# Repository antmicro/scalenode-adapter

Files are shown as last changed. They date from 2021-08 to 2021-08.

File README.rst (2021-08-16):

=================
Scalenode Adapter
=================

Copyright (c) 2021 `Antmicro <https://www.antmicro.com>`_

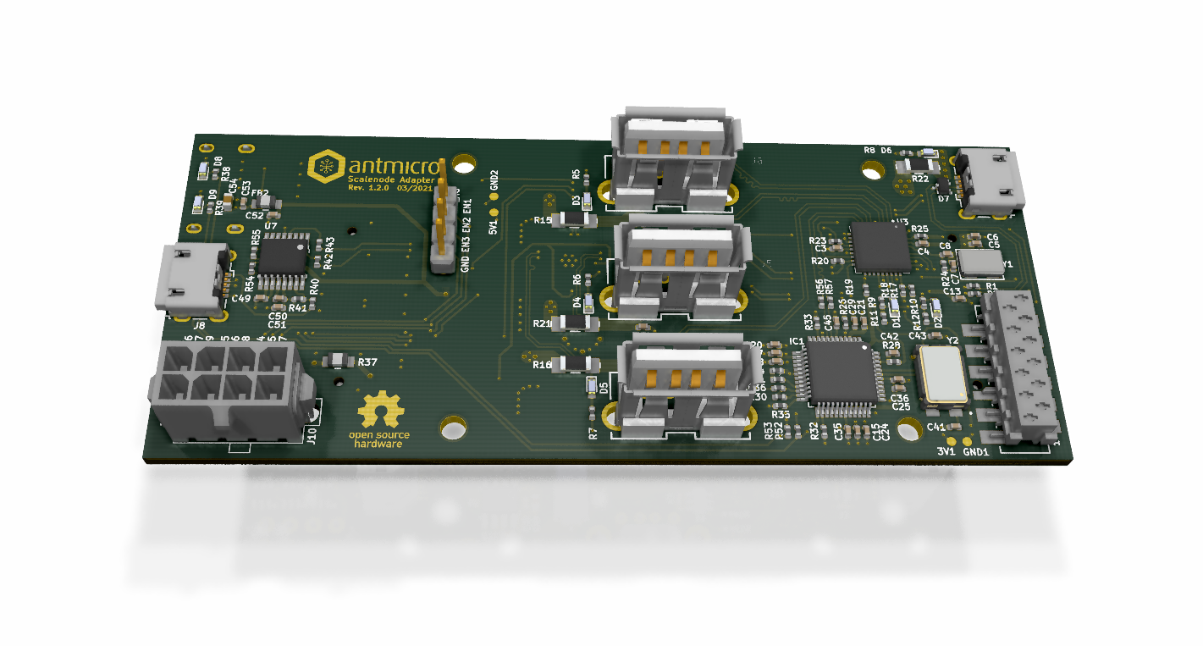
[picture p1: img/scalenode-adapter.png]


Overview
--------

This repository contains design files of the expansion card for the Antmicro's `Scalenode <https://github.com/antmicro/scalenode>`_ platform.
This expansion card exposes three USB host ports with independent supply current monitoring for each port.
This allows for using the Scalenode to interact with external, FPGA-driven evaluation boards such as the Digilent `Arty A7 <https://reference.digilentinc.com/programmable-logic/arty/start>`_ boards.
The design files were prepared in KiCad.
An initial production release for the design was fabricated as prototypes and these are now being tested.

Repository structure
--------------------
The main repository directory contains KiCad PCB project files, a LICENSE and README.
The remaining files are stored in the following directories:

* ``lib`` - contains the component libraries
* ``img`` - contains graphics for this README

Key Features
------------

* Expansion board for the Scalenode module
* Supports up to three Digilet Arty boards
* On-board current measurement circuitry

License
=======

`Apache-2.0 <LICENSE>`_

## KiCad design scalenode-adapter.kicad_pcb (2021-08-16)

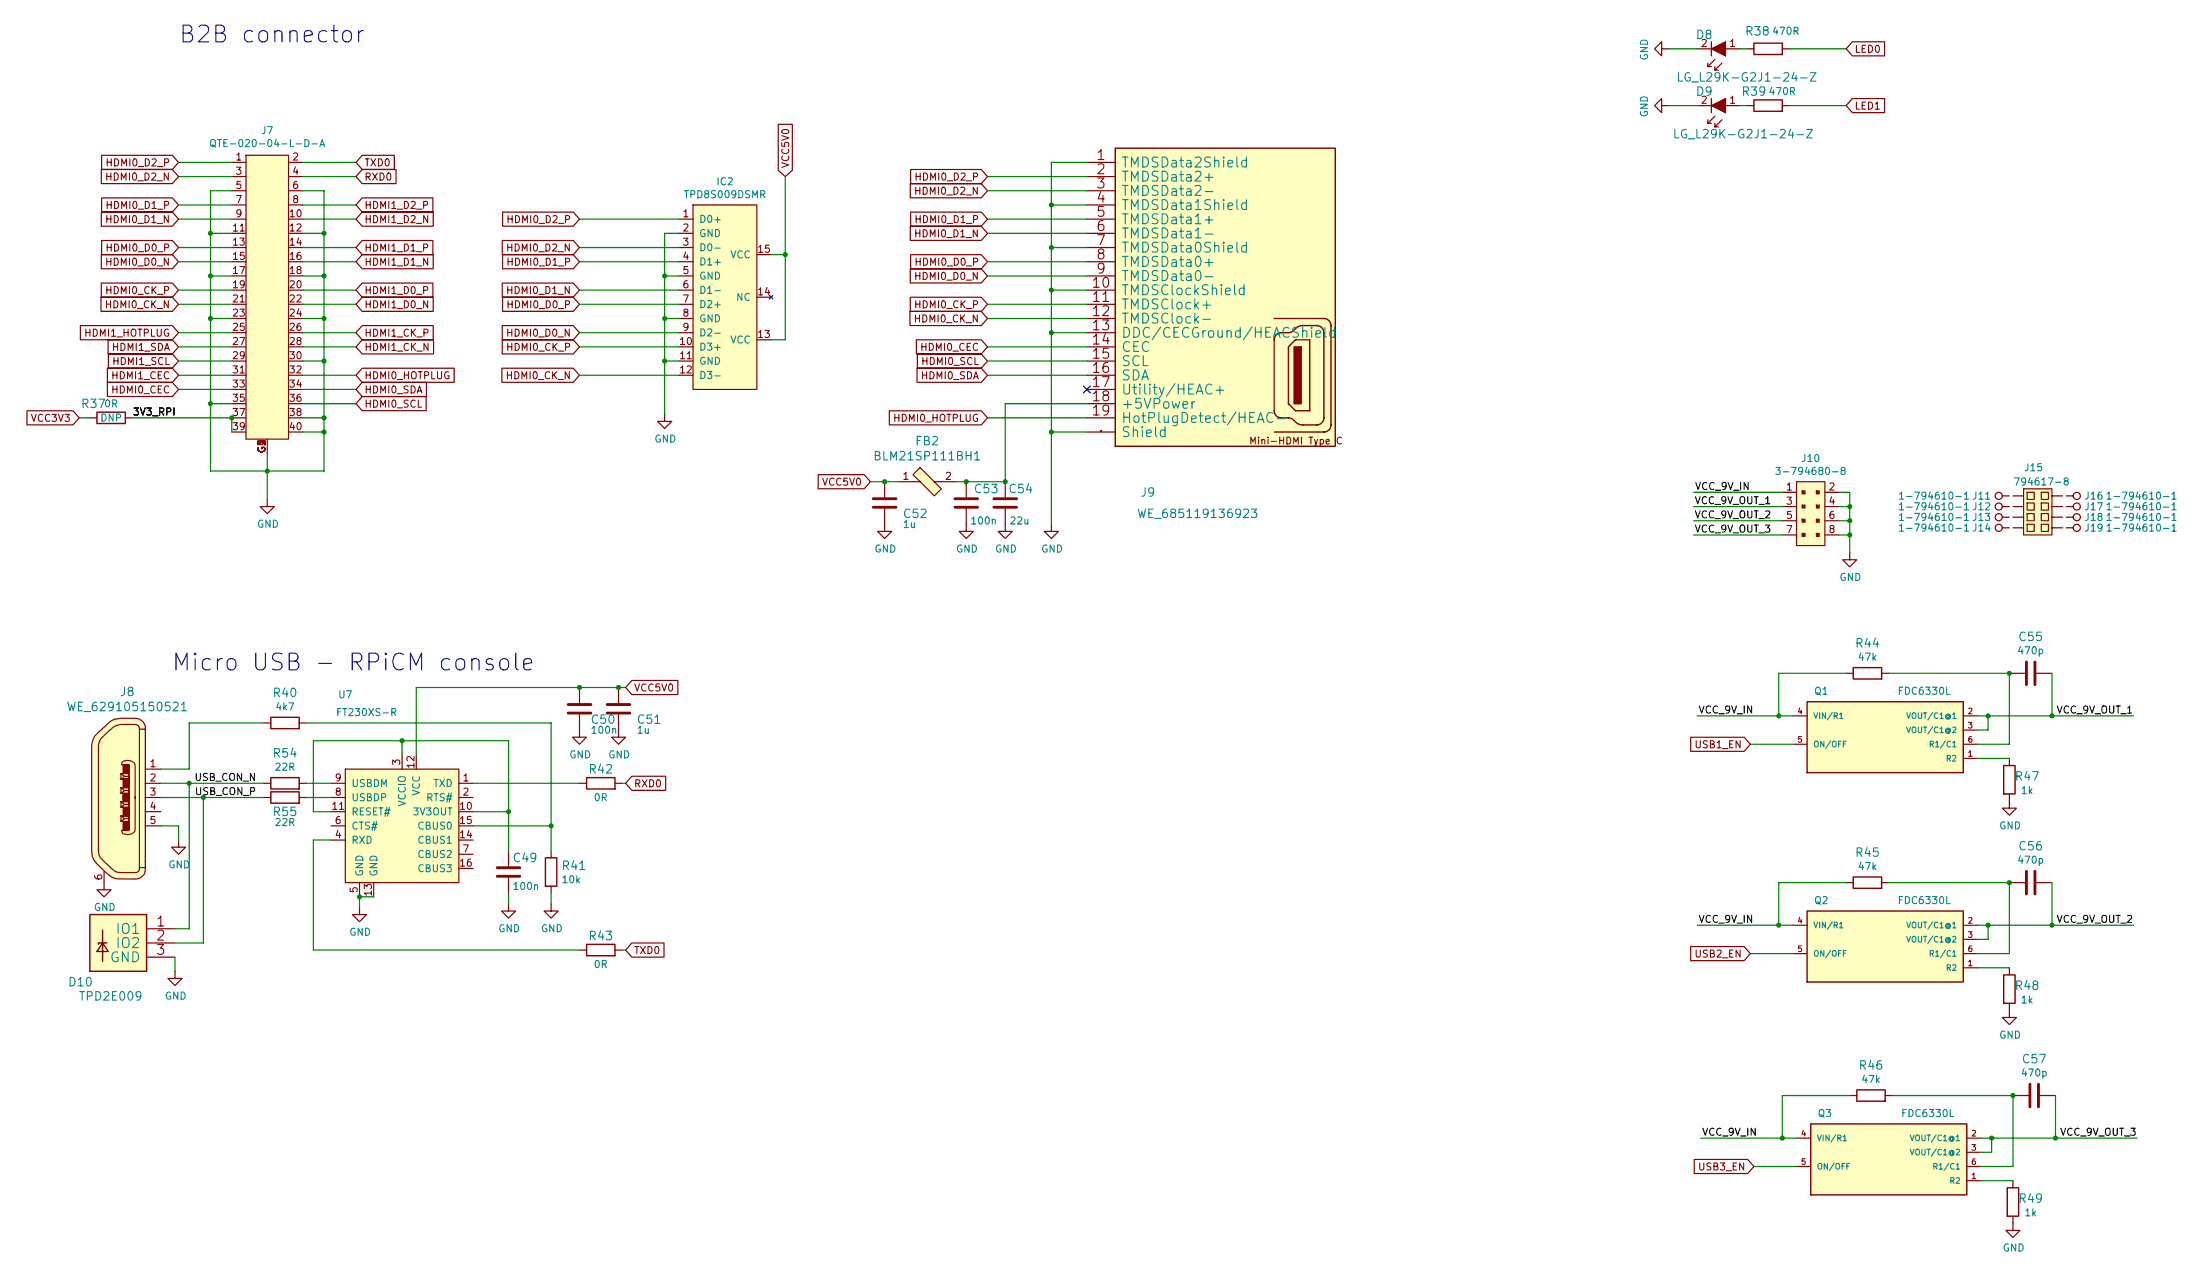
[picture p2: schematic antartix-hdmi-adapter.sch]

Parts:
C49, C50, C53: C_100n_0402; 0402-cap; MPN 0402X104K6R3CT
C51, C52: C_1u_0402; 0402-cap; MPN C1005X6S1A105K050BC
C54: C_22u_0603; 0603-cap; MPN GRM188R60J226MEA0D
C55, C56, C57: C_470p_0402; 0402-cap; MPN 0402B471K250CT
D8, D9: LG_L29K-G2J1-24-Z; LED_0603; MPN LG L29K-G2J1-24-Z
D10: TPD2E009; SOT-3; MPN TPD2E009DRTR
FB2: BLM21SP111BH1; 0805-res; MPN BLM21SP111BH1D
IC2: TPD8S009DSMR; R-PDSO-N15; MPN TPD8S009DSMR
J7: QTE-020-04-L-D-A; MPN QTE-020-04-L-D-A
J8: WE_629105150521; USB_Micro_B_Female_629105150521; MPN 629105150521
J9: WE_685119136923; MPN 685119136923
J10: 3-794680-8; MPN 3-794680-8
J11, J12, J13, J14, J16, J17, J18, J19: 1-794610-1; MPN 1-794610-1
J15: 794617-8; 3-794617-8; MPN 794617-8
Q1, Q2, Q3: FDC6330L; MPN FDC6330L
R37: R_0R_0805; 0805-res; MPN CRCW08050000Z0EA
R38, R39: R_470R_0402; 0402-res; MPN CRCW0402470RFKED
R40: R_4k7_0402; 0402-res; MPN ERJ2GEJ472X
R41: R_10k_0402; 0402-res; MPN CRCW040210K0FKEDHP
R42, R43: R_0R_0402; 0402-res; MPN ERJ2GE0R00X
R44, R45, R46: R_47k_0402; 0402-res; MPN MCMR04X4702FTL
R47, R48, R49: R_1k_0402; 0402-res; MPN CR0402-FX-1001GLF
R54, R55: R_22R_0402; 0402-res; MPN CRCW040222R0FKED
U7: FT230XS-R; SSOP-16_W3.90mm; MPN FT230XS-R

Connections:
/antartix hdmi adapter/3V3_RPI: J7.37, J7.39, R37.2
/antartix hdmi adapter/USB_CON_N: D10.1 (IO1), J8.2, R54.1
/antartix hdmi adapter/USB_CON_P: D10.2 (IO2), J8.3, R55.1
/antartix hdmi adapter/VCC_9V_IN: J10.1, Q1.4 (VIN/R1), Q2.4 (VIN/R1), Q3.4 (VIN/R1), R44.1, R45.1, R46.1
/antartix hdmi adapter/VCC_9V_OUT_1: C55.1, J10.3, Q1.2 (VOUT/C1@1), Q1.3 (VOUT/C1@2)
/antartix hdmi adapter/VCC_9V_OUT_2: C56.1, J10.5, Q2.2 (VOUT/C1@1), Q2.3 (VOUT/C1@2)
/antartix hdmi adapter/VCC_9V_OUT_3: C57.1, J10.7, Q3.2 (VOUT/C1@1), Q3.3 (VOUT/C1@2)
GND: C49.2, C50.2, C51.2, C52.2, C53.2, C54.1, D8.2, D9.2, D10.3 (GND), IC2.2 (GND), IC2.5 (GND), IC2.8 (GND), IC2.11 (GND), J7.5, J7.6, J7.11, J7.12, J7.17, J7.18, J7.23, J7.24, J7.30, J7.35, J7.38, J7.40, J7.G1, J7.G2, J7.G3, J7.G4, J8.5, J8.6, J9.1 (TMDSData2Shield), J9.4 (TMDSData1Shield), J9.7 (TMDSData0Shield), J9.10 (TMDSClockShield), J9.13 (DDC/CECGround/HEACShield), J9.Shell (Shield), J10.2, J10.4, J10.6, J10.8, R41.2, R47.2, R48.2, R49.2, U7.5 (GND), U7.13 (GND); also elsewhere on the board
HDMI0_CEC: J7.33, J9.14 (CEC)
HDMI0_CK_N: IC2.12 (D3-), J7.21, J9.12 (TMDSClock-)
HDMI0_CK_P: IC2.10 (D3+), J7.19, J9.11 (TMDSClock+)
HDMI0_D0_N: IC2.9 (D2-), J7.15, J9.9 (TMDSData0-)
HDMI0_D0_P: IC2.7 (D2+), J7.13, J9.8 (TMDSData0+)
HDMI0_D1_N: IC2.6 (D1-), J7.9, J9.6 (TMDSData1-)
HDMI0_D1_P: IC2.4 (D1+), J7.7, J9.5 (TMDSData1+)
HDMI0_D2_N: IC2.3 (D0-), J7.3, J9.3 (TMDSData2-)
HDMI0_D2_P: IC2.1 (D0+), J7.1, J9.2 (TMDSData2+)
HDMI0_HOTPLUG: J7.32, J9.19 (HotPlugDetect/HEAC-)
HDMI0_SCL: J7.36, J9.15 (SCL)
HDMI0_SDA: J7.34, J9.16 (SDA)
HDMI1_CEC: J7.31
HDMI1_CK_N: J7.28
HDMI1_CK_P: J7.26
HDMI1_D0_N: J7.22
HDMI1_D0_P: J7.20
HDMI1_D1_N: J7.16
HDMI1_D1_P: J7.14
HDMI1_D2_N: J7.10
HDMI1_D2_P: J7.8
HDMI1_HOTPLUG: J7.25
HDMI1_SCL: J7.29
HDMI1_SDA: J7.27
LED0: R38.2; also elsewhere on the board
LED1: R39.2; also elsewhere on the board
unnamed: C49.1, U7.3 (VCCIO), U7.10 (3V3OUT), U7.11 (RESET#)
unnamed: C53.1, C54.2, FB2.2, J9.18 (+5VPower)
unnamed: C55.2, Q1.6 (R1/C1), R44.2
unnamed: C56.2, Q2.6 (R1/C1), R45.2
unnamed: C57.2, Q3.6 (R1/C1), R46.2
unnamed: D8.1, R38.1
unnamed: D9.1, R39.1
unnamed: J8.1, R40.1
unnamed: Q1.1 (R2), R47.1
unnamed: Q2.1 (R2), R48.1
unnamed: Q3.1 (R2), R49.1
unnamed: R40.2, R41.1, U7.15 (CBUS0)
unnamed: R42.1, U7.1 (TXD)
unnamed: R43.1, U7.4 (RXD)
unnamed: R54.2, U7.9 (USBDM)
unnamed: R55.2, U7.8 (USBDP)
RXD0: J7.4, R42.2
TXD0: J7.2, R43.2
USB1_EN: Q1.5 (ON/OFF); also elsewhere on the board
USB2_EN: Q2.5 (ON/OFF); also elsewhere on the board
USB3_EN: Q3.5 (ON/OFF); also elsewhere on the board
VCC3V3: R37.1; also elsewhere on the board
VCC5V0: C50.1, C51.1, C52.1, FB2.1, IC2.13 (VCC), IC2.15 (VCC), U7.12 (VCC); also elsewhere on the board

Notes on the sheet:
B2B connector
Micro USB - RPiCM console

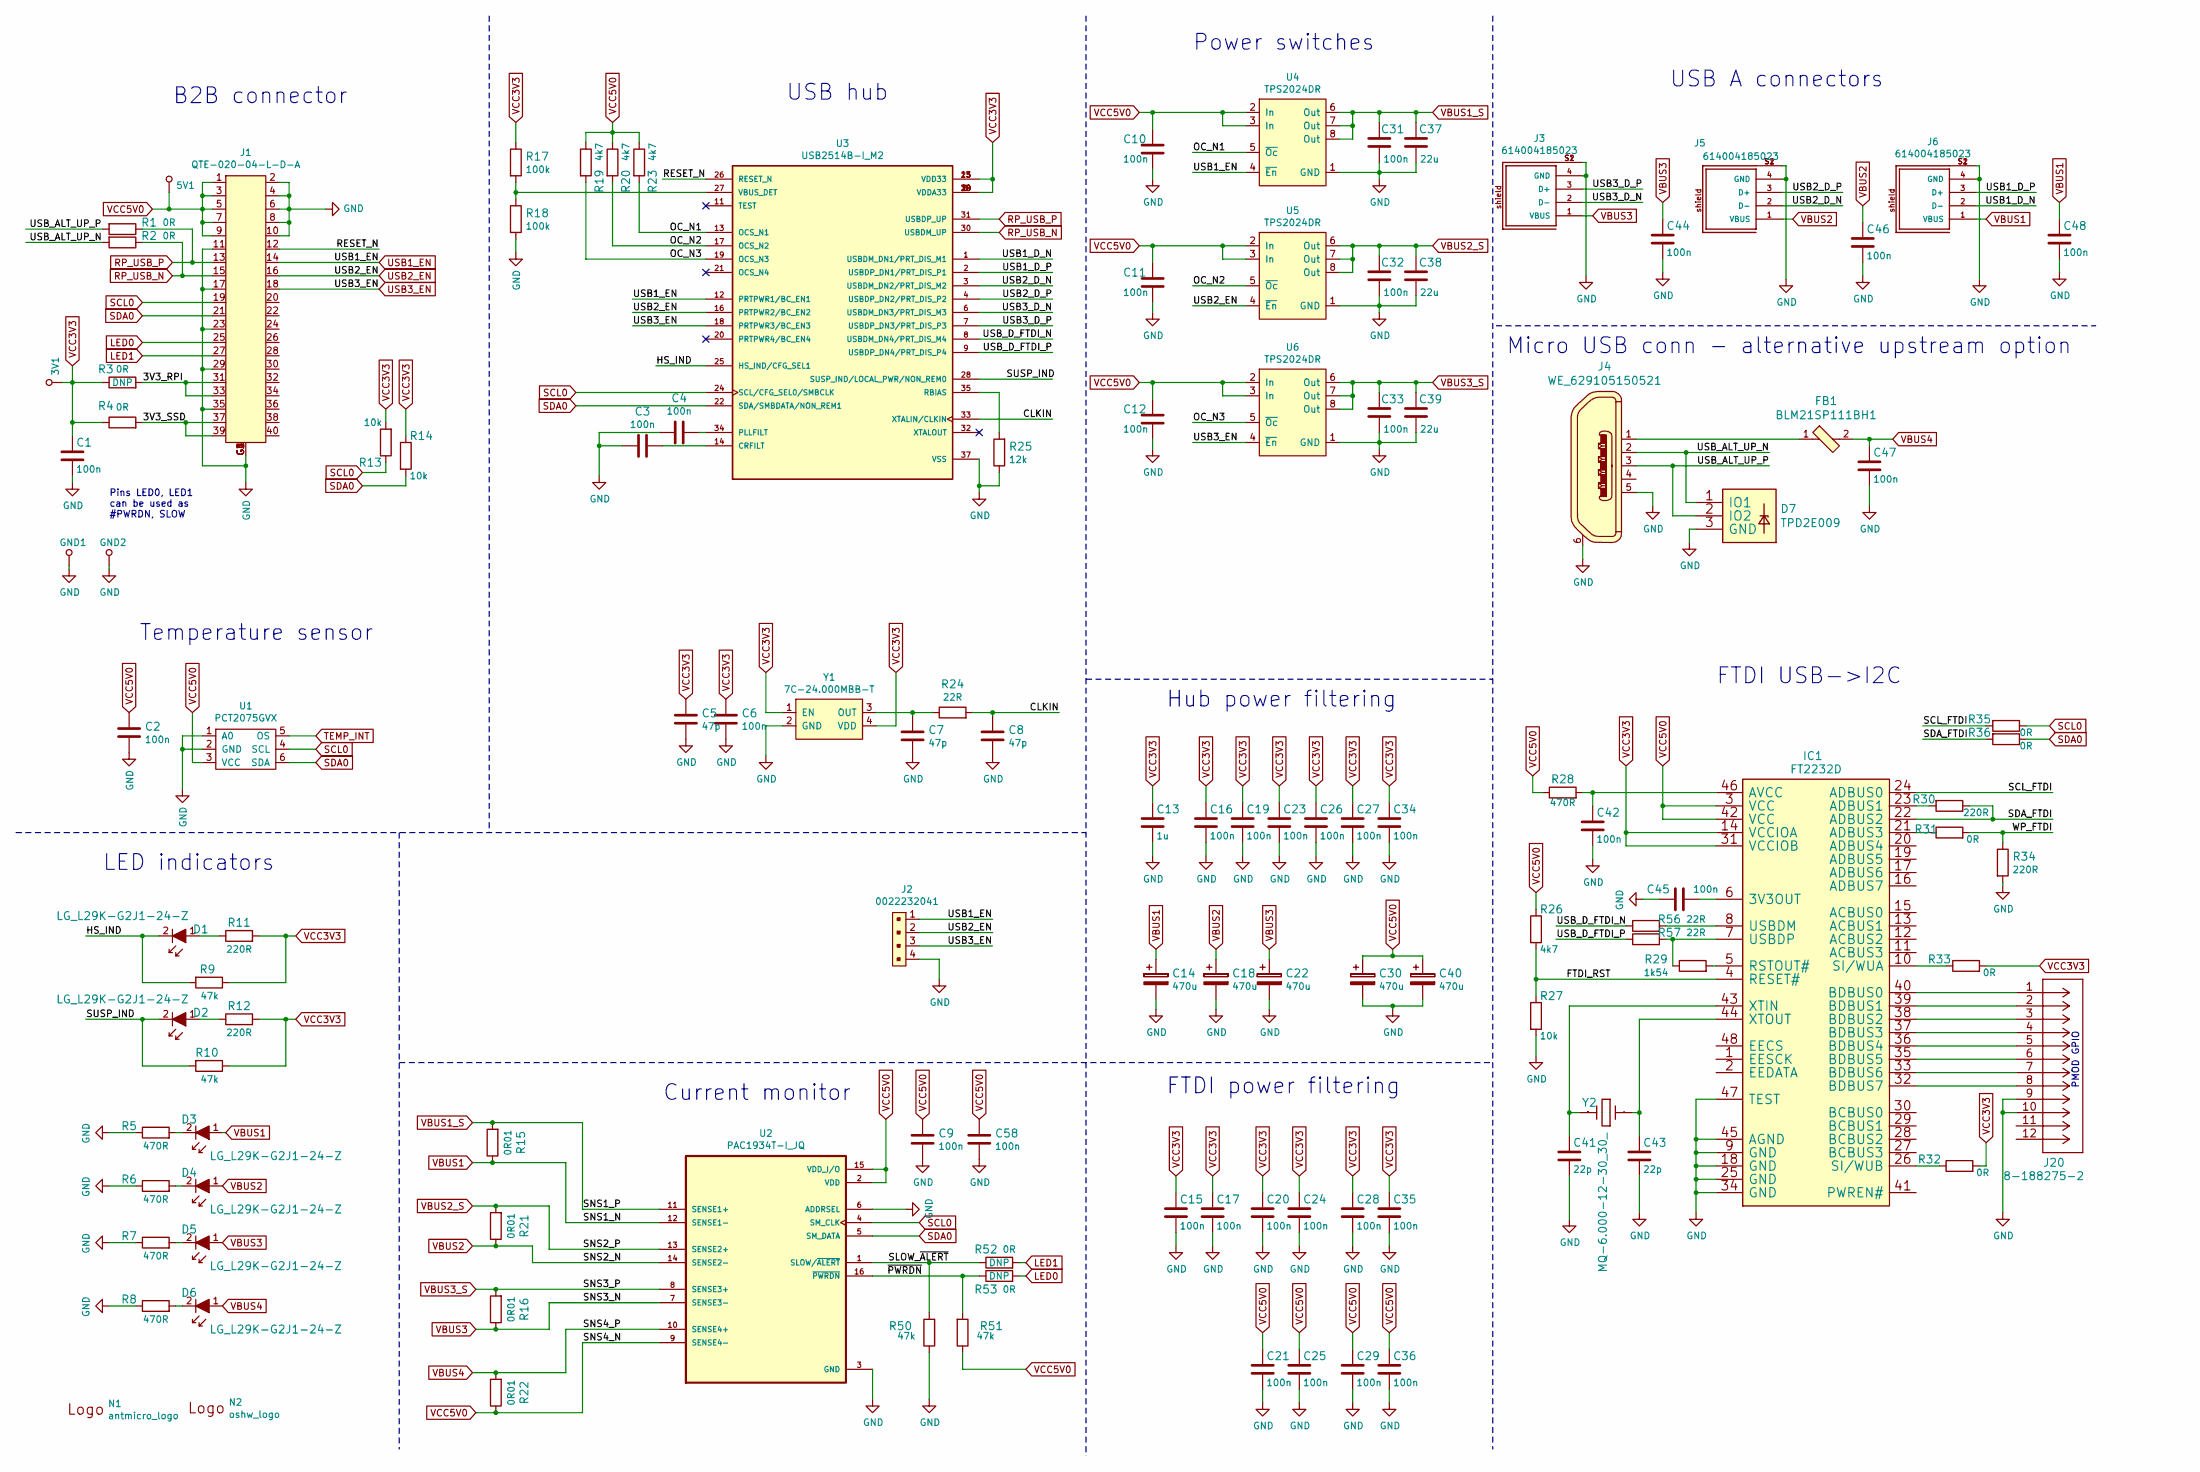
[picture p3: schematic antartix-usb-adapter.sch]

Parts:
3V1, 5V1: TP_SMD1MM; Testpoint_smd_1mm
C1, C2, C3, C4, C6, C9, C15, C16, C17, C19, C20, C21, C23, C24, C25, C26, C27, C28, C29, C31, C32, C33, C34, C35, C36, C42, C44, C45, C46, C47, C48, C58: C_100n_0402; 0402-cap; MPN 0402X104K6R3CT
C5, C7, C8: C_47p_0402; 0402-cap; MPN C0402C470J5GACTU
C10, C11, C12: C_100n_0603; 0603-cap; MPN 0603YC104KAZ2A
C13: C_1u_0402; 0402-cap; MPN C1005X6S1A105K050BC
C14, C18, C22, C30, C40: C_470u_KEMET_D; KEMET_D; MPN TR3D477M6R3C0200
C37, C38, C39: C_22u_0603; 0603-cap; MPN GRM188R60J226MEA0D
C41, C43: C_22p_0402; 0402-cap; MPN CC0402JRNPO9BN220
D1, D2, D3, D4, D5, D6: LG_L29K-G2J1-24-Z; LED_0603; MPN LG L29K-G2J1-24-Z
D7: TPD2E009; SOT-3; MPN TPD2E009DRTR
FB1: BLM21SP111BH1; 0805-res; MPN BLM21SP111BH1D
GND1, GND2: TP_SMD1MM; Testpoint_smd_1mm
IC1: FT2232D; LQFP-48_7x7mm; MPN FT2232D-REEL
J1: QTE-020-04-L-D-A; MPN QTE-020-04-L-D-A
J2: 0022232041; PinHeader_1x4_P2.54mm_Drill1.02mm; MPN 0022232041
J3, J5, J6: 614004185023; MPN 614004185023
J4: WE_629105150521; USB_Micro_B_Female_629105150521; MPN 629105150521
J20: 8-188275-2; MPN 8-188275-2
N1: antmicro_logo; antmicro-logo_scaled_15mm
N2: oshw_logo; oshw-logo
R1, R2, R31, R32, R33, R35, R36, R52, R53: R_0R_0402; 0402-res; MPN ERJ2GE0R00X
R3, R4: R_0R_0805; 0805-res; MPN CRCW08050000Z0EA
R5, R6, R7, R8, R28: R_470R_0402; 0402-res; MPN CRCW0402470RFKED
R9, R10, R50, R51: R_47k_0402; 0402-res; MPN MCMR04X4702FTL
R11, R12, R30, R34: R_220R_0402; 0402-res; MPN ERJ2GEJ221X
R13, R14, R27: R_10k_0402; 0402-res; MPN CRCW040210K0FKEDHP
R15, R16, R21, R22: R_0R01_1206; 1206-res; MPN ERJMP2KF10MU
R17, R18: R_100k_0402; 0402-res; MPN CRCW0402100KFKEDHP
R19, R20, R23, R26: R_4k7_0402; 0402-res; MPN ERJ2GEJ472X
R24, R56, R57: R_22R_0402; 0402-res; MPN CRCW040222R0FKED
R25: R_12k_0402; 0402-res; MPN CRCW040212K0FKEDHP
R29: R_1k54_0402; 0402-res; MPN CRCW04021K54FKED.
U1: PCT2075GVX; SOT95P275X110-6N; MPN PCT2075GVX
U2: PAC1934T-I_JQ; QFN65P400X400X55-17N
U3: USB2514B-I_M2; QFN50P600X600X100-37N; MPN USB2514B-I/M2
U4, U5, U6: TPS2024DR; SOIC-8_W3.9mm; MPN TPS2024DR
Y1: 7C-24.000MBB-T; MPN 7C-24.000MBB-T
Y2: MQ-6.000-12-30_30_; Crystal_5x7mm; MPN MQ-6.000-12-30/30/-40+85

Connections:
/antartix usb adapter/3V3_RPI: J1.31, J1.33, R3.2
/antartix usb adapter/3V3_SSD: J1.37, J1.39, R4.2
/antartix usb adapter/CLKIN: C8.1, R24.2, U3.33 (XTALIN/CLKIN)
/antartix usb adapter/FTDI_RST: IC1.4 (RESET#), R26.2, R27.1
/antartix usb adapter/HS_IND: D1.2, R9.2, U3.25 (HS_IND/CFG_SEL1)
/antartix usb adapter/OC_N1: R23.2, U3.13 (OCS_N1), U4.5 (~Oc)
/antartix usb adapter/OC_N2: R20.2, U3.17 (OCS_N2), U5.5 (~Oc)
/antartix usb adapter/OC_N3: R19.2, U3.19 (OCS_N3), U6.5 (~Oc)
/antartix usb adapter/RESET_N: J1.12, U3.26 (RESET_N)
/antartix usb adapter/SCL_FTDI: IC1.24 (ADBUS0), R35.2
/antartix usb adapter/SDA_FTDI: IC1.22 (ADBUS2), R30.1, R36.2
/antartix usb adapter/SLOW_~ALERT: R50.2, R52.1, U2.1 (SLOW/~ALERT)
/antartix usb adapter/SUSP_IND: D2.2, R10.2, U3.28 (SUSP_IND/LOCAL_PWR/NON_REM0)
/antartix usb adapter/USB1_D_N: J6.2 (D-), U3.1 (USBDM_DN1/PRT_DIS_M1)
/antartix usb adapter/USB1_D_P: J6.3 (D+), U3.2 (USBDP_DN1/PRT_DIS_P1)
/antartix usb adapter/USB2_D_N: J5.2 (D-), U3.3 (USBDM_DN2/PRT_DIS_M2)
/antartix usb adapter/USB2_D_P: J5.3 (D+), U3.4 (USBDP_DN2/PRT_DIS_P2)
/antartix usb adapter/USB3_D_N: J3.2 (D-), U3.6 (USBDM_DN3/PRT_DIS_M3)
/antartix usb adapter/USB3_D_P: J3.3 (D+), U3.7 (USBDP_DN3/PRT_DIS_P3)
/antartix usb adapter/USB_ALT_UP_N: D7.1 (IO1), J4.2, R2.2
/antartix usb adapter/USB_ALT_UP_P: D7.2 (IO2), J4.3, R1.2
/antartix usb adapter/USB_D_FTDI_N: R56.1, U3.8 (USBDM_DN4/PRT_DIS_M4)
/antartix usb adapter/USB_D_FTDI_P: R57.1, U3.9 (USBDP_DN4/PRT_DIS_P4)
/antartix usb adapter/WP_FTDI: R31.2, R34.1
/antartix usb adapter/~PWRDN: R51.2, R53.1, U2.16 (~PWRDN)
GND: C1.2, C2.2, C3.2, C4.2, C5.2, C6.2, C7.2, C8.2, C9.2, C10.2, C11.2, C12.2, C13.2, C14.2, C15.2, C16.2, C17.2, C18.2, C19.2, C20.2, C21.2, C22.2, C23.2, C24.2, C25.2, C26.2, C27.2, C28.2, C29.2, C30.2, C31.1, C32.1, C33.1, C34.2, C35.2, C36.2, C37.1, C38.1, C39.1, C40.2, C41.2, C42.2, C43.2, C44.2, C45.2, C46.2, C47.2, C48.2, C58.2, D7.3 (GND), GND1.1, GND2.1, IC1.9 (GND), IC1.18 (GND), IC1.25 (GND), IC1.34 (GND), IC1.45 (AGND), IC1.47 (TEST), J1.2, J1.4, J1.6, J1.8, J1.10, J1.11, J1.17, J1.23, J1.29, J1.35, J1.G1, J1.G2, J1.G3, J1.G4, J2.4, J3.4 (GND), J3.S1, J3.S2, J4.5, J4.6, J5.4 (GND), J5.S1, J5.S2, J6.4 (GND), J6.S1, J6.S2, J20.9, J20.10, R5.1, R6.1, R7.1, R8.1, R18.2, R25.1, R27.2, R34.2, R50.1, U1.1 (A0), U1.2 (GND), U2.3 (GND), U2.6 (ADDRSEL), U2.17, U3.37 (VSS), U4.1 (GND), U5.1 (GND), U6.1 (GND), Y1.2 (GND); also elsewhere on the board
LED0: J1.25, R53.2; also elsewhere on the board
LED1: J1.27, R52.2; also elsewhere on the board
unnamed: C3.1, U3.14 (CRFILT)
unnamed: C4.1, U3.34 (PLLFILT)
unnamed: C7.1, R24.1, Y1.3 (OUT)
unnamed: C41.1, IC1.43 (XTIN), Y2.1
unnamed: C42.1, IC1.46 (AVCC), R28.2
unnamed: C43.1, IC1.44 (XTOUT), Y2.3
unnamed: C45.1, IC1.6 (3V3OUT)
unnamed: D1.1, R11.1
unnamed: D2.1, R12.1
unnamed: D3.2, R5.2
unnamed: D4.2, R6.2
unnamed: D5.2, R7.2
unnamed: D6.2, R8.2
unnamed: FB1.1, J4.1
unnamed: IC1.5 (RSTOUT#), R29.2
unnamed: IC1.7 (USBDP), R29.1, R57.2
unnamed: IC1.8 (USBDM), R56.2
unnamed: IC1.10 (SI/WUA), R33.1
unnamed: IC1.21 (ADBUS3), R31.1
unnamed: IC1.23 (ADBUS1), R30.2
unnamed: IC1.26 (SI/WUB), R32.1
unnamed: IC1.32 (BDBUS7), J20.8
unnamed: IC1.33 (BDBUS6), J20.7
unnamed: IC1.35 (BDBUS5), J20.6
unnamed: IC1.36 (BDBUS4), J20.5
unnamed: IC1.37 (BDBUS3), J20.4
unnamed: IC1.38 (BDBUS2), J20.3
unnamed: IC1.39 (BDBUS1), J20.2
unnamed: IC1.40 (BDBUS0), J20.1
unnamed: R17.2, R18.1, U3.27 (VBUS_DET)
unnamed: R25.2, U3.35 (RBIAS)
RP_USB_N: J1.15, R2.1, U3.30 (USBDM_UP)
RP_USB_P: J1.13, R1.1, U3.31 (USBDP_UP)
SCL0: J1.19, R13.1, R35.1, U1.4 (SCL), U2.4 (SM_CLK), U3.24 (SCL/CFG_SEL0/SMBCLK)
SDA0: J1.21, R14.2, R36.1, U1.6 (SDA), U2.5 (SM_DATA), U3.22 (SDA/SMBDATA/NON_REM1)
TEMP_INT: U1.5 (OS)
USB1_EN: J1.14, J2.1, U3.12 (PRTPWR1/BC_EN1), U4.4 (~En); also elsewhere on the board
USB2_EN: J1.16, J2.2, U3.16 (PRTPWR2/BC_EN2), U5.4 (~En); also elsewhere on the board
USB3_EN: J1.18, J2.3, U3.18 (PRTPWR3/BC_EN3), U6.4 (~En); also elsewhere on the board
VBUS1: C14.1, C48.1, D3.1, J6.1 (VBUS), R15.1, U2.12 (SENSE1-)
VBUS1_S: C31.2, C37.2, R15.2, U2.11 (SENSE1+), U4.6 (Out), U4.7 (Out), U4.8 (Out)
VBUS2: C18.1, C46.1, D4.1, J5.1 (VBUS), R21.1, U2.14 (SENSE2-)
VBUS2_S: C32.2, C38.2, R21.2, U2.13 (SENSE2+), U5.6 (Out), U5.7 (Out), U5.8 (Out)
VBUS3: C22.1, C44.1, D5.1, J3.1 (VBUS), R16.1, U2.7 (SENSE3-)
VBUS3_S: C33.2, C39.2, R16.2, U2.8 (SENSE3+), U6.6 (Out), U6.7 (Out), U6.8 (Out)
VBUS4: C47.1, D6.1, FB1.2, R22.2, U2.10 (SENSE4+)
VCC3V3: 3V1.1, C1.1, C5.1, C6.1, C13.1, C15.1, C16.1, C17.1, C19.1, C20.1, C23.1, C24.1, C26.1, C27.1, C28.1, C34.1, C35.1, IC1.14 (VCCIOA), IC1.31 (VCCIOB), R3.1, R4.1, R9.1, R10.1, R11.2, R12.2, R13.2, R14.1, R17.1, R32.2, R33.2, U3.5 (VDDA33), U3.10 (VDDA33), U3.15 (VDD33), U3.23 (VDD33), U3.29 (VDDA33), U3.36 (VDDA33), Y1.1 (EN), Y1.4 (VDD); also elsewhere on the board
VCC5V0: 5V1.1, C2.1, C9.1, C10.1, C11.1, C12.1, C21.1, C25.1, C29.1, C30.1, C36.1, C40.1, C58.1, IC1.3 (VCC), IC1.42 (VCC), J1.1, J1.3, J1.5, J1.7, J1.9, R19.1, R20.1, R22.1, R23.1, R26.1, R28.1, R51.1, U1.3 (VCC), U2.2 (VDD), U2.9 (SENSE4-), U2.15 (VDD_I/O), U4.2 (In), U4.3 (In), U5.2 (In), U5.3 (In), U6.2 (In), U6.3 (In); also elsewhere on the board

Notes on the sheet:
Hub power filtering
Micro USB conn - alternative upstream option
FTDI power filtering
FTDI USB->I2C
USB A connectors
LED indicators
Power switches
Current monitor
USB hub
Temperature sensor
B2B connector
Pins LED0, LED1 can be used as #PWRDN, SLOW
PMOD GPIO

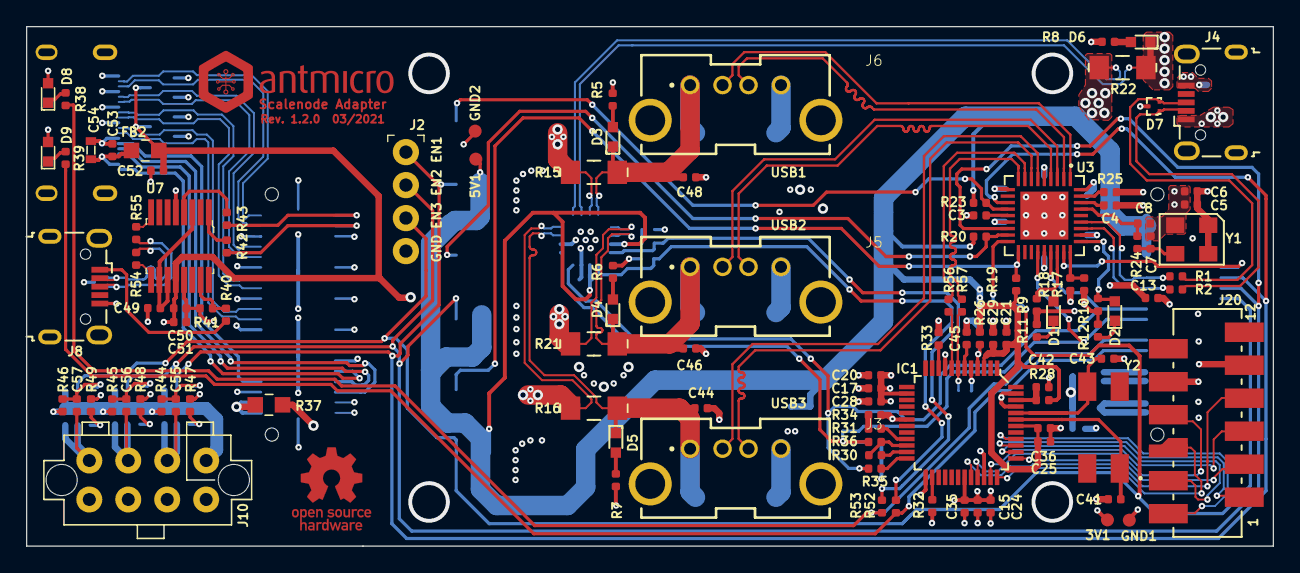
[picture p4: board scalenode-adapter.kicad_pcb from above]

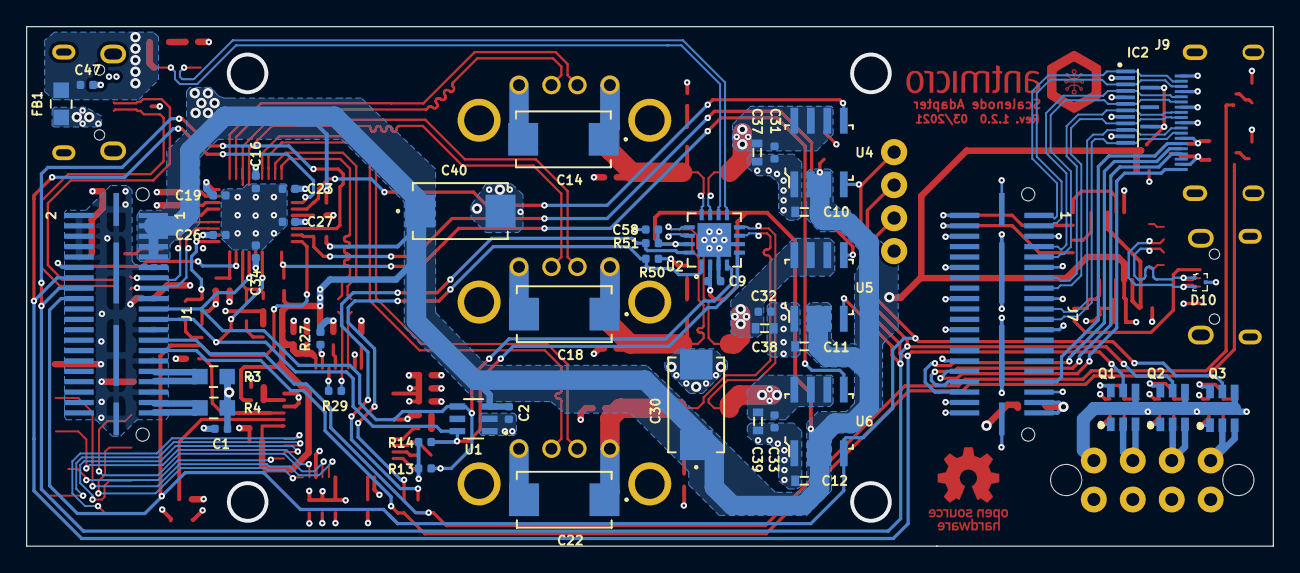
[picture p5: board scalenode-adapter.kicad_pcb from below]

Board: 4 copper layers, 96.0 x 40.0 mm, 167 parts (56 on the bottom side), 112 nets.

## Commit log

2021-08-16 Initial commit. Add initial design files
    [antartix-arty-controller.kicad_pcb, antartix-arty-controller.sch]
2021-08-16 Add power switches, add current monitor circuits
    [antartix-arty-controller.sch]
2021-08-16 Add 3x vertical USB connector
    [antartix-arty-controller.sch]
2021-08-16 Add changes to schematic
    -Add pull up resistors on I2C
    -Add Voltage devider on VBUS_DET
    -Add Hi-Speed upstream port indicator LED
    [antartix-arty-controller.sch]
2021-08-16 Add initial component placement
    [antartix-arty-controller.kicad_pcb]
2021-08-16 Update schematic
    [antartix-arty-controller.sch]
2021-08-16 Add FTDI and clean up schematic
    [antartix-arty-controller.kicad_pcb, antartix-arty-controller.sch]
2021-08-16 Update PCB outline
    [antartix-arty-controller.kicad_pcb]
2021-08-16 Fix outline
    [antartix-arty-controller.kicad_pcb, antartix-arty-controller.sch]
2021-08-16 Update current monitoring circuit
    [antartix-arty-controller.sch]
2021-08-16 Layout update (WIP)
    [antartix-arty-controller.kicad_pcb, antartix-arty-controller.sch]
2021-08-16 Fix optional micro USB connection
    [antartix-arty-controller.sch]
2021-08-16 Component placement done
    [antartix-arty-controller.kicad_pcb, antartix-arty-controller.sch]
2021-08-16 Modified layout, routed USB. Now routing current sensing
    [antartix-arty-controller.kicad_pcb, antartix-arty-controller.sch]
2021-08-16 Problem with power switches
    [antartix-arty-controller.kicad_pcb, antartix-arty-controller.sch]
2021-08-16 Replace power switches
    [antartix-arty-controller.kicad_pcb, antartix-arty-controller.sch]
2021-08-16 Layout done
    [antartix-arty-controller.kicad_pcb]
2021-08-16 Routing control signals
    [antartix-arty-controller.kicad_pcb, antartix-arty-controller.sch]
2021-08-16 Board routed
    [antartix-arty-controller.kicad_pcb, antartix-arty-controller.sch]
2021-08-16 review amendments
    [antartix-arty-controller.kicad_pcb, antartix-arty-controller.sch]
2021-08-16 Combine schematic sheets - Initial commit of the next PCB revision
    [antartix-arty-controller.sch, antartix-hdmi-adapter.sch]
2021-08-16 Remove redundant 3V3 traces
    [antartix-arty-controller.kicad_pcb]
2021-08-16 Add hierarchical structure
    [antartix-arty-controller.kicad_pcb, antartix-arty-controller.sch, antartix-hdmi-adapter.sch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]
2021-08-16 Connect UART(GPIO14 & GPIO15)to BDBUS of FTDI
    [antartix-arty-controller.kicad_pcb, antartix-hdmi-adapter.sch, antartix-usb-adapter.sch]
2021-08-16 Remove second HDMI and add LEDs to schematic
    [antartix-hdmi-adapter.sch]
2021-08-16 Add aux power supply to the schematic sheet
    [antartix-arty-controller.sch, antartix-usb-adapter.sch, aux-power-supply.sch]
2021-08-16 Add component placement
    [antartix-arty-controller.kicad_pcb, antartix-hdmi-adapter.sch, aux-power-supply.sch]
2021-08-16 Rename alt upstream lanes
    [antartix-usb-adapter.sch]
2021-08-16 Add FTDI and LEDs
    [antartix-hdmi-adapter.sch, antartix-usb-adapter.sch, aux-power-supply.sch]
2021-08-16 Add HDMI control signals, change connector to mini HDMI
    [antartix-hdmi-adapter.sch]
2021-08-16 Fix power keys
    [antartix-arty-controller.sch, antartix-hdmi-adapter.sch, antartix-usb-adapter.sch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]
2021-08-16 Change aux power connector
    [antartix-hdmi-adapter.sch]
2021-08-16 Reduce board size, update connector placement
    [antartix-arty-controller.kicad_pcb, antartix-hdmi-adapter.sch, antartix-usb-adapter.sch]
2021-08-16 Route buttons and HDMI
    [antartix-arty-controller.kicad_pcb, antartix-hdmi-adapter.sch, antartix-usb-adapter.sch]
2021-08-16 Route console and HDMI control signals
    [antartix-arty-controller.kicad_pcb, antartix-hdmi-adapter.sch, antartix-usb-adapter.sch]
2021-08-16 Add 22R to FTDI
    [antartix-arty-controller.kicad_pcb]
2021-08-16 Remove TXD1 and RXD1 labels
    [antartix-usb-adapter.sch]
2021-08-16 Place logotypes on PCB
    [antartix-arty-controller.kicad_pcb]
2021-08-16 Remove redundant spacers and 3D model of additional conenctor
    [antartix-arty-controller.kicad_pcb, antartix-hdmi-adapter.sch]
2021-08-16 Redesign HDMI and Micro USB layout
    [antartix-arty-controller.kicad_pcb]
2021-08-16 Clean the designators
    [antartix-arty-controller.kicad_pcb]
2021-08-16 Add local libraries
    [antartix-arty-controller.kicad_pcb, antartix-hdmi-adapter.sch, antartix-usb-adapter.sch]
2021-08-16 Added micromatch-12 connector as PMOD GPIO. Bumped to 1.2.0
    [antartix-arty-controller.kicad_pcb, antartix-arty-controller.sch, antartix-hdmi-adapter.sch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]
2021-08-16 Add MPNs
    [antartix-hdmi-adapter.sch, antartix-usb-adapter.sch]
2021-08-16 Update libraries fields
    [antartix-arty-controller.kicad_pcb, antartix-hdmi-adapter.sch, antartix-usb-adapter.sch]
2021-08-16 Update naming convention
    [antartix-hdmi-adapter.sch, antartix-usb-adapter.sch, scalenode-adapter.kicad_pcb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]
2021-08-16 Connect EP of U2 to GND to resolve DRC
    [scalenode-adapter.kicad_pcb]
2021-08-16 Resolve annular ring DRC issues
    [scalenode-adapter.kicad_pcb]
2021-08-16 Assign revision code to schematic sheets
    [hdmi-adapter.sch, scalenode-adapter.sch, usb-adapter.sch]

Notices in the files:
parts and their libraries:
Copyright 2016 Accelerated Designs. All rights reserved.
